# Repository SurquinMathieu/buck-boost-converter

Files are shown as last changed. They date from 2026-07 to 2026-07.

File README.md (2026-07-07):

# Buck-Boost DC/DC Converter

A 4-switch synchronous buck-boost converter built around an STM32G431CBT6, with a digital PI control loop, USB CDC telemetry, and a real-time web dashboard for monitoring and control.

## Overview

This project implements a 4-switch buck-boost DC/DC converter. The STM32 runs a 300 kHz PWM control loop with real-time voltage sensing, feedforward + PI regulation, soft-start, and software UVLO protection. A companion web dashboard connects over USB to display live VIN/VOUT readings and lets you adjust the output setpoint from a browser.

**Key specifications**

| Parameter | Value |
|---|---|
| Input voltage | 10 – 40 V |
| Output voltage | 3 – 15 V |
| Max output current| 3 A |
| Switching frequency | 300 kHz |
| MCU | STM32G431CBT6 (Cortex-M4, 170 MHz) |
| Topology | 4-switch buck-boost |

## Features

- Digital PI control with feedforward
- Soft-start on power-up and on setpoint changes
- Software UVLO (on: 12 V, off: 10 V) backed by a hardware UVLO on the gate-driver supply
- Dual-simultaneous ADC sampling of VIN and VOUT, triggered by the timer
- USB CDC telemetry (VIN, VOUT, target, duty cycle)
- Web dashboard (Python/WebSocket backend + HTML/JS frontend) for live plotting and setpoint control
- State-machine firmware architecture designed to be extended to boost and full buck-boost modes

## Hardware

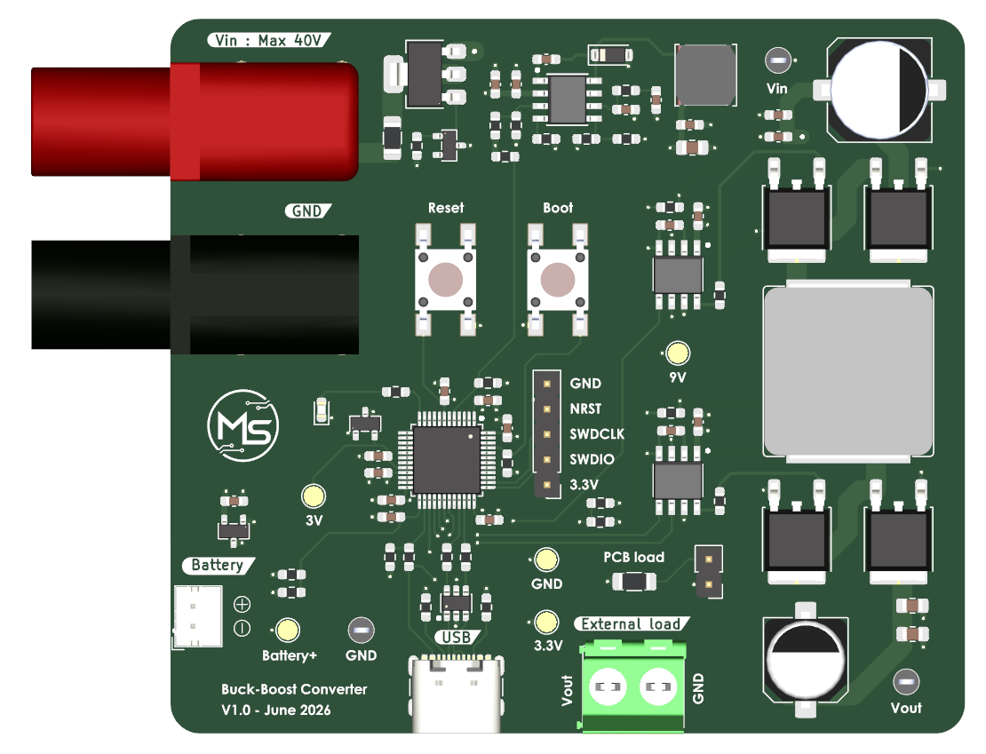
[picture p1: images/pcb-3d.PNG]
PCB


The converter uses four N-channel MOSFETs driven by two half-bridge gate drivers.

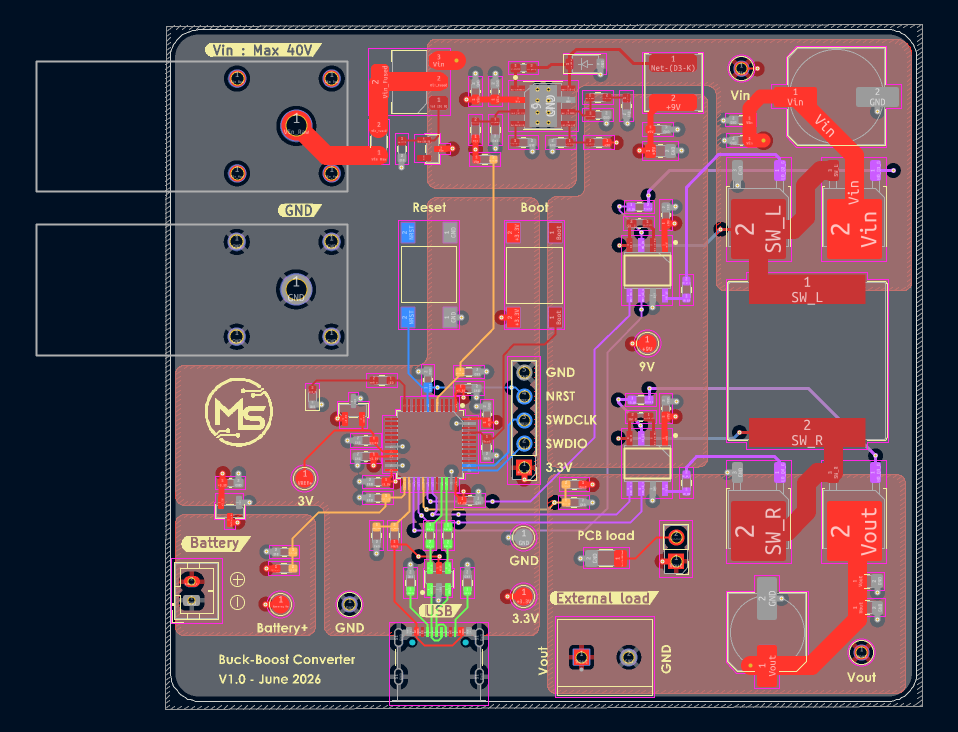
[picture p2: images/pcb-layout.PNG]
PCB layout


See [`hardware/kicad`](hardware/kicad) for the full KiCad project and [`hardware/bom`](hardware/bom) for the bill of materials.

## Firmware

See [`firmware/`](firmware) for the STM32CubeIDE project.

### Building

1. Open the project in STM32CubeIDE (`firmware/DC-DC-Converter.ioc`)
2. Build and flash to an STM32G431CBT6
3. Connect over USB

## Dashboard

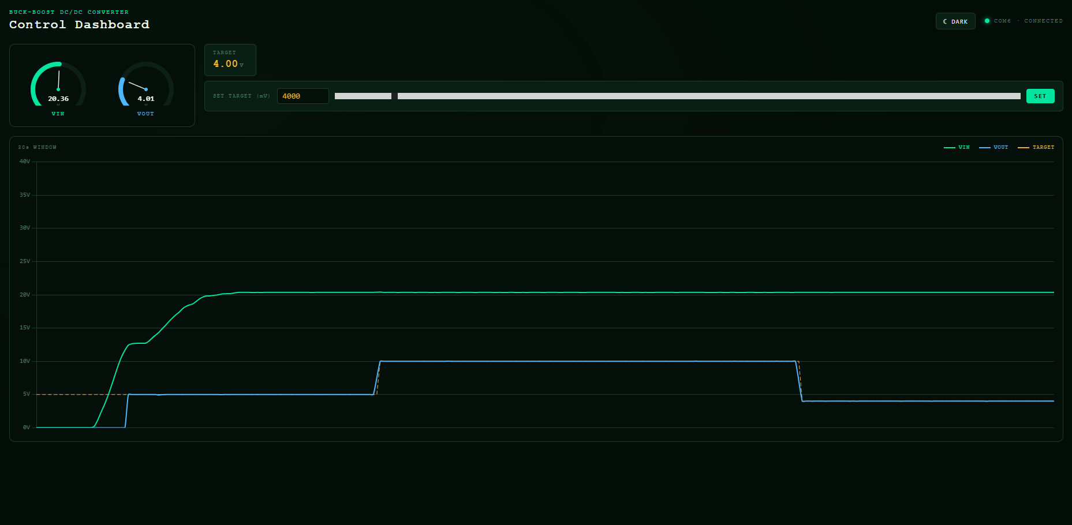
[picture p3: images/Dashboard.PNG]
Dashboard


The dashboard connects to the board's virtual COM port and streams VIN/VOUT/target data to a browser in real time over a local WebSocket, with a live waveform plot and a setpoint control.

### Running it

```bash
cd dashboard
pip install pyserial websockets
python server.py
```

Then open `index.html` in a browser. Update the `PORT` variable in `server.py` to match your board's COM port.

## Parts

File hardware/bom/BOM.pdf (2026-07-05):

Designator C1 | Qty 1 | Component Ceramic capacitor 560pF — 50V X7R — 0603 | Manufacturer Samsung | MPN / Reference CL10C561JB8NFNC | Unit Price (€) 0,039 € | Unit Price × Qty (€) 0,04 €
C2 – C17 | 16 | Ceramic capacitor 100nF — 50V X7R — 0603 | Samsung | CL10B104KB8NNNC | 0,023 € | 0,37 €
C18 | 1 | Ceramic capacitor 330nF — 50V X7R — 0603 | TDK | CGA3E3X7R1H334K080AB | 0,200 € | 0,20 €
C19 | 1 | Ceramic capacitor 1µF — 25V X7R — 0603 | Samsung | CL10B105KA8NNNC | 0,031 € | 0,03 €
C20, C21 | 2 | Ceramic capacitor 2.2µF — 50V X5R — 0603 | Murata | GRT188R61H225KE13D | 0,009 € | 0,02 €
C22, C23, C24 | 3 | Ceramic capacitor 10µF — 16V X5R — 0805 | Samsung | CL21A106KOQNNNE | 0,052 € | 0,16 €
C25 | 1 | Electrolytic Capacitor 100µF — 50V 20% — 10x10mm | Panasonic | EEH-ZA1H101V | 1,390 € | 1,39 €
C26 | 1 | Electrolytic Capacitor 220µF — 25V 20% — 8x8mm | Panasonic | EEH-ZA1E221P | 1,460 € | 1,46 €
D1 | 1 | Zener diode 10V 300mW — SOT-23 | Diotec Semiconductor | BZX84C10 | 0,150 € | 0,15 €
D2 | 1 | Red LED — 0603 | Würth Elektronik | 150060SS75000 | 0,130 € | 0,13 €
D3 | 1 | Schottky diode 60V 1A — SOD-123 | ROHM Semiconductor | RB162MM-60TR | 0,330 € | 0,33 €
D4 | 1 | TVS diode 5.25V bidirectional — SOT-23-6 | STMicroelectronics | USBLC6-2SC6Y | 0,460 € | 0,46 €
F1 | 1 | Fuse 6A — 1206 | Bel Fuse | 0685T6000-01 | 0,570 € | 0,57 €
J1 | 1 | Banana jack 4mm red | Cliff Electronic | FCR7350R | 4,870 € | 4,87 €
J2 | 1 | Banana jack 4mm black | Cliff Electronic | FCR7350B | 4,870 € | 4,87 €
J3 | 1 | Connector JST-PH 2-pin | JST | B2B-PH-K-S | 0,100 € | 0,10 €
J4 | 1 | USB Type-C 16P | GCT | USB4105-GF-A | 0,690 € | 0,69 €
J5 | 1 | Pin header 1×02 2.54mm vertical | — | — | 0,000 € | 0,00 €
J6 | 1 | Terminal block 2P 5.08mm | TE Connectivity | 282837-2 | 0,760 € | 0,76 €
J7 | 1 | Pin header 1×05 2.54mm vertical | — | — | 0,000 € | 0,00 €
L1 | 1 | Inductor 15µH 2.5A 75mΩ — 6x6mm | TDK | VLS6045EX-150M | 0,320 € | 0,32 €
L2 | 1 | Inductor 39µH 9.2A 48mΩ — 16,9x16,9mm | Bourns | SRP1770TA-390M | 3,170 € | 3,17 €
Q1, Q2, Q3, Q4 | 4 | MOSFET N-ch 60V 45A — TO-252-3 | Infineon | IPD053N06NATMA1 | 2,140 € | 8,56 €
Q5 | 1 | MOSFET P-ch 60V 18.2A — SOT-223 | Diodes Incorporated | DMP6023LE-13 | 1,110 € | 1,11 €
R1 – R4 | 4 | Resistor 4.7Ω 5% 1/8W — 0603 | Vishay | CRCW06034R70JNEA | 0,026 € | 0,10 €
R5, R6 | 2 | Resistor 22Ω 5% 1/5W — 0603 | TE Connectivity | CRGH0603J22R | 0,035 € | 0,07 €
R7 | 1 | Resistor 68Ω 1% 1/10W — 0603 | Yageo | RC0603FR-0768RL | 0,021 € | 0,02 €
R8 | 1 | Resistor 1kΩ 1% 1/2W — 1206 | Stackpole Electronics | RNCP1206FTD1K00 | 0,015 € | 0,02 €
R9 | 1 | Resistor 1.4kΩ 1% 1/10W — 0603 | Bourns | CR0603-FX-1401ELF | 0,019 € | 0,02 €
R10, R11 | 2 | Resistor 5.1kΩ 1% 1/10W — 0603 | Yageo | RC0603FR-075K1L | 0,021 € | 0,04 €
R12 – R15 | 4 | Resistor 10kΩ 1% 1/10W — 0603 | Yageo | RC0603FR-0710KL | 0,021 € | 0,08 €
R16 | 1 | Resistor 33kΩ 1% 1/10W — 0603 | Yageo | RC0603FR-0733KL | 0,021 € | 0,02 €
R17 | 1 | Resistor 40.2kΩ 1% 1/10W — 0603 | Yageo | RC0603FR-0740K2L | 0,021 € | 0,02 €
R18 | 1 | Resistor 61.9kΩ 1% 1/10W — 0603 | Bourns | CR0603-FX-6192ELF | 0,018 € | 0,02 €
R19 | 1 | Resistor 68kΩ 1% 1/10W — 0603 | Yageo | RC0603FR-0768KL | 0,021 € | 0,02 €
R20, R21 | 2 | Resistor 100kΩ 1% 1/10W — 0603 | Yageo | RC0603FR-07100KL | 0,021 € | 0,04 €
R22 | 1 | Resistor 102kΩ 0.1% 1/10W — 0603 | Yageo | RT0603BRD07102KL | 0,057 € | 0,06 €
R23 | 1 | Resistor 124kΩ 1% 1/10W — 0603 | Yageo | RC0603FR-07124KL | 0,021 € | 0,02 €
R24 | 1 | Resistor 180kΩ 1% 1/10W — 0603 | Yageo | RC0603FR-07180KL | 0,021 € | 0,02 €
R25 | 1 | Resistor 249kΩ 0.1% 1/10W — 0603 | Panasonic | ERA-3AEB2493V | 0,090 € | 0,09 €
R26 | 1 | Resistor 590kΩ 1% 1/8W — 0603 | Vishay | CRCW0603590KFKEA | 0,027 € | 0,03 €
SW1, SW2 | 2 | Switch SPST-NO 50mA 12V — SMD | Same Sky | TS04-66-50-BK-260-SMT | 0,151 € | 0,30 €
TP1, TP2, TP6 | 3 | Testpoint miniature | Keystone Electronics | 5001 | 0,260 € | 0,78 €
U1 | 1 | MCU STM32G431CBT6 — Cortex-M4 170MHz FPU — LQFP-48 | STMicroelectronics | STM32G431CBT6 | 5,150 € | 5,15 €
U2 | 1 | LDO 3.3V 250mA — SOT-23 | Microchip Technology | MCP1700T-3302E/TT | 0,440 € | 0,44 €
U3 | 1 | Voltage reference 3.000V 0.1% — SOT-23 | Texas Instruments | REF3030EAIDBZR | 1,010 € | 1,01 €
U4 | 1 | Buck converter — HSOIC-8 | Texas Instruments | TPS54360BDDAR | 3,980 € | 3,98 €
U5, U6 | 2 | Half-bridge gate driver — SOIC-8 | Texas Instruments | UCC27282DR | 1,700 € | 3,40 €
TOTAL | 82 | | | | | 45,51 €

## BILL OF MATERIALS — Buck-Boost DC/DC Converter

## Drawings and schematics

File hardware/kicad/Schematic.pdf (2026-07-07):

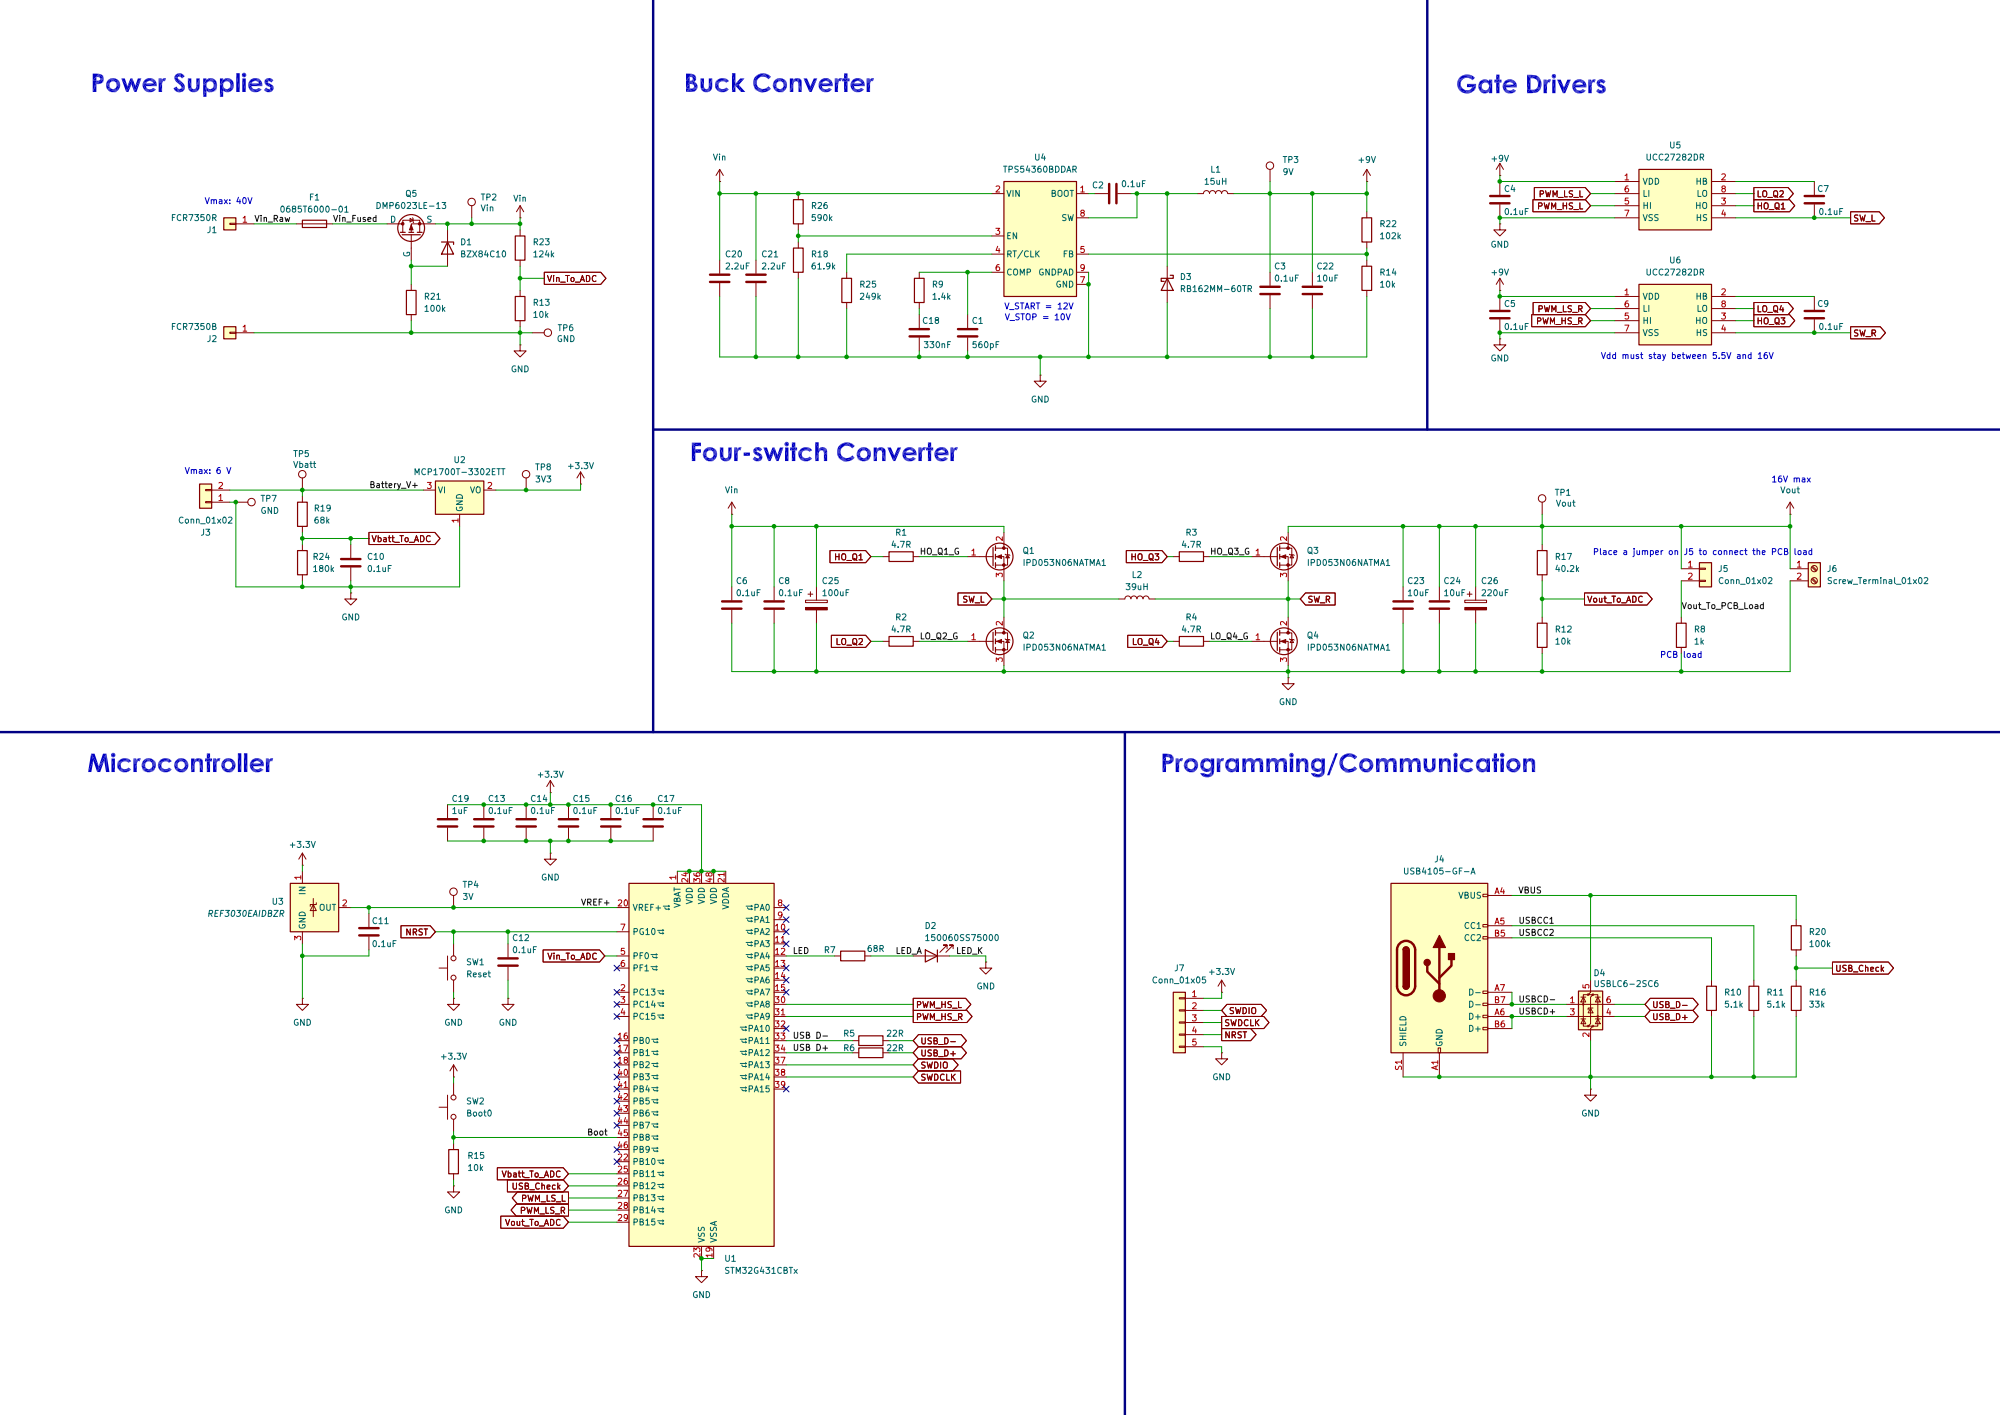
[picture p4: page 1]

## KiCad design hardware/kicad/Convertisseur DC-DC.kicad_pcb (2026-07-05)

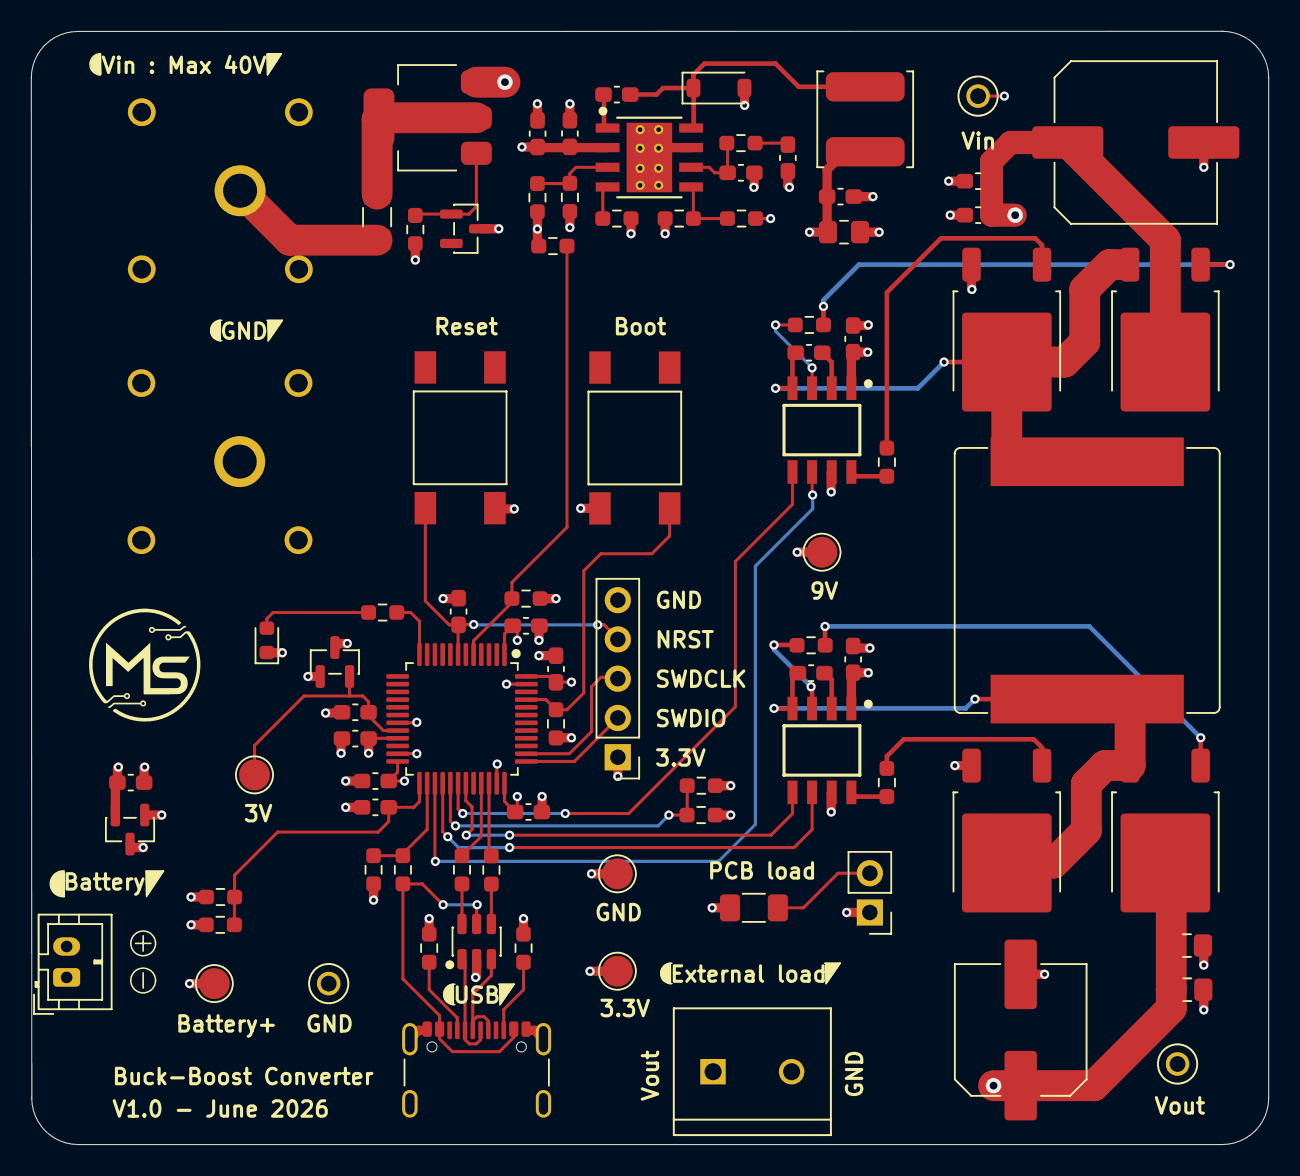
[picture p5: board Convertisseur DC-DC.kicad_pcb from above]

Board: 4 copper layers, 80.0 x 72.0 mm, 87 parts (0 on the bottom side), 53 nets.

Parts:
C1: 560pF; C_0603_1608Metric_Pad1.08x0.95mm_HandSolder
C2, C3, C4, C5, C6, C7, C8, C9, C10, C11, C12, C13, C14, C15, C16, C17: 0.1uF; C_0603_1608Metric_Pad1.08x0.95mm_HandSolder
C18: 330nF; C_0603_1608Metric_Pad1.08x0.95mm_HandSolder
C19: 1uF; C_0603_1608Metric_Pad1.08x0.95mm_HandSolder
C20, C21: 2.2uF; C_0603_1608Metric_Pad1.08x0.95mm_HandSolder
C22, C23, C24: 10uF; C_0805_2012Metric_Pad1.18x1.45mm_HandSolder
C25: 100uF; C_Elec_10x10.2
C26: 220uF; C_Elec_8x10.2
D1: BZX84C10; SOT-23
D2: 150060SS75000; LED_0603_1608Metric
D3: RB162MM-60TR; D_SOD-123
D4: USBLC6-2SC6; SOT-23-6
F1: 0685T6000-01; Fuse_1206_3216Metric_Pad1.42x1.75mm_HandSolder
J1: FCR7350R; FCR7350
J2: FCR7350B; FCR7350
J3: Conn_01x02; JST_PH_B2B-PH-K_1x02_P2.00mm_Vertical
J4: USB4105-GF-A; USB_C_Receptacle_GCT_USB4105-xx-A_16P_TopMnt_Horizontal
J5: Conn_01x02; PinHeader_1x02_P2.54mm_Vertical
J6: Screw_Terminal_01x02; TE_282837-2
J7: Conn_01x05; PinHeader_1x05_P2.54mm_Vertical
L1: 15uH; L_TDK_VLS6045EX_VLS6045AF
L2: 39uH; L_Bourns_SRP1770TA_16.9x16.9mm
Q1, Q2, Q3, Q4: IPD053N06NATMA1; TO-252-2
Q5: DMP6023LE-13; SOT-223-3_TabPin2
R1, R2, R3, R4: 4.7R; R_0603_1608Metric_Pad0.98x0.95mm_HandSolder
R5, R6: 22R; R_0603_1608Metric_Pad0.98x0.95mm_HandSolder
R7: 68R; R_0603_1608Metric_Pad0.98x0.95mm_HandSolder
R8: 1k; R_1206_3216Metric_Pad1.30x1.75mm_HandSolder
R9: 1.4k; R_0603_1608Metric_Pad0.98x0.95mm_HandSolder
R10, R11: 5.1k; R_0603_1608Metric_Pad0.98x0.95mm_HandSolder
R12, R13, R14, R15: 10k; R_0603_1608Metric_Pad0.98x0.95mm_HandSolder
R16: 33k; R_0603_1608Metric_Pad0.98x0.95mm_HandSolder
R17: 40.2k; R_0603_1608Metric_Pad0.98x0.95mm_HandSolder
R18: 61.9k; R_0603_1608Metric_Pad0.98x0.95mm_HandSolder
R19: 68k; R_0603_1608Metric_Pad0.98x0.95mm_HandSolder
R20, R21: 100k; R_0603_1608Metric_Pad0.98x0.95mm_HandSolder
R22: 102k; R_0603_1608Metric_Pad0.98x0.95mm_HandSolder
R23: 124k; R_0603_1608Metric_Pad0.98x0.95mm_HandSolder
R24: 180k; R_0603_1608Metric_Pad0.98x0.95mm_HandSolder
R25: 249k; R_0603_1608Metric_Pad0.98x0.95mm_HandSolder
R26: 590k; R_0603_1608Metric_Pad0.98x0.95mm_HandSolder
SW1: Reset; SW_TS04-66-50-BK-260-SMT
SW2: Boot0; SW_TS04-66-50-BK-260-SMT
TP1: Vout; 5001
TP2: Vin; 5001
TP3: 9V; TestPoint_Pad_D2.0mm
TP4: 3V; TestPoint_Pad_D2.0mm
TP5: Vbatt; TestPoint_Pad_D2.0mm
TP6: GND; 5001
TP7: GND; TestPoint_Pad_D2.0mm
TP8: 3V3; TestPoint_Pad_D2.0mm
U1: STM32G431CBTx; LQFP-48_7x7mm_P0.5mm
U2: MCP1700T-3302ETT; SOT-23
U3: REF3030EAIDBZR; SOT-23
U4: TPS54360BDDAR; TI_SO-PowerPAD-8_ThermalVias
U5, U6: UCC27282DR

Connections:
+3.3V: C13.1, C14.1, C15.1, C16.1, C17.1, C19.1, J7.1, SW2.2, TP8.1, U1.1 (VBAT), U1.21 (VDDA), U1.24 (VDD), U1.36 (VDD), U1.48 (VDD), U2.2 (VO), U3.1 (IN)
+9V: C3.1, C4.1, C5.1, C22.1, L1.2, R22.1, TP3.1, U5.1 (VDD), U6.1 (VDD)
/Battery_V+: J3.2, R19.1, TP5.1, U2.3 (VI)
/Boot: R15.1, SW2.1, U1.45 (PB8)
/HO_Q1_G: Q1.1 (G), R1.2
/HO_Q3_G: Q3.1 (G), R3.2
/LED: R7.1, U1.12 (PA4)
/LED_A: D2.2 (A), R7.2
/LO_Q2_G: Q2.1 (G), R2.2
/LO_Q4_G: Q4.1 (G), R4.2
/USB D+: R6.1, U1.34 (PA12)
/USB D-: R5.1, U1.33 (PA11)
/USBCC1: J4.A5 (CC1), R11.1
/USBCC2: J4.B5 (CC2), R10.1
/USBCD+: D4.3 (I/O2), J4.A6 (D+), J4.B6 (D+)
/USBCD-: D4.1 (I/O1), J4.A7 (D-), J4.B7 (D-)
/VBUS: D4.5 (VBUS), J4.A4 (VBUS), J4.A9 (VBUS), J4.B4 (VBUS), J4.B9 (VBUS), R20.1
/VREF+: C11.1, TP4.1, U1.20 (VREF+), U3.2 (OUT)
/Vin_Fused: F1.2, Q5.2 (D)
/Vin_Raw: F1.1, J1.1
/Vout_To_PCB_Load: J5.2, R8.1
GND: C1.2, C3.2, C4.2, C5.2, C6.2, C8.2, C10.2, C11.2, C12.2, C13.2, C14.2, C15.2, C16.2, C17.2, C18.2, C19.2, C20.2, C21.2, C22.2, C23.2, C24.2, C25.2, C26.2, D2.1 (K), D3.2 (A), D4.2 (GND), J2.1, J3.1, J4.A1 (GND), J4.A12 (GND), J4.B1 (GND), J4.B12 (GND), J4.S1 (SHIELD), J6.2, J7.5, Q2.3 (S), Q4.3 (S), R8.2, R10.2, R11.2, R12.2, R13.2, R14.2, R15.2, R16.2, R18.2, R21.2, R24.2, R25.2, SW1.1, TP6.1, TP7.1, U1.19 (VSSA), U1.23 (VSS), U1.35 (VSS), U1.47 (VSS), U2.1 (GND), U3.3 (GND), U4.7 (GND), U4.9 (GNDPAD), U5.7 (VSS), U6.7 (VSS)
HO_Q1: R1.1, U5.3 (HO)
HO_Q3: R3.1, U6.3 (HO)
LO_Q2: R2.1, U5.8 (LO)
LO_Q4: R4.1, U6.8 (LO)
NRST: C12.1, J7.4, SW1.2, U1.7 (PG10)
unnamed: C18.1, R9.2
unnamed: D1.1 (A), Q5.1 (G), R21.1
unnamed: C2.2, D3.1 (K), L1.1, U4.8 (SW)
unnamed: C2.1, U4.1 (BOOT)
unnamed: C1.1, R9.1, U4.6 (COMP)
unnamed: R18.1, R26.2, U4.3 (EN)
unnamed: R14.1, R22.2, U4.5 (FB)
unnamed: R25.1, U4.4 (RT/CLK)
unnamed: C7.1, U5.2 (HB)
unnamed: C9.1, U6.2 (HB)
PWM_HS_L: U1.30 (PA8), U5.5 (HI)
PWM_HS_R: U1.31 (PA9), U6.5 (HI)
PWM_LS_L: U1.27 (PB13), U5.6 (LI)
PWM_LS_R: U1.28 (PB14), U6.6 (LI)
SWDCLK: J7.3, U1.38 (PA14)
SWDIO: J7.2, U1.37 (PA13)
SW_L: C7.2, L2.1, Q1.3 (S), Q2.2 (D), U5.4 (HS)
SW_R: C9.2, L2.2, Q3.3 (S), Q4.2 (D), U6.4 (HS)
USB_Check: R16.1, R20.2, U1.26 (PB12)
USB_D+: D4.4 (I/O2), R6.2
USB_D-: D4.6 (I/O1), R5.2
Vbatt_To_ADC: C10.1, R19.2, R24.1, U1.25 (PB11)
Vin: C6.1, C8.1, C20.1, C21.1, C25.1, D1.3 (K), Q1.2 (D), Q5.3 (S), R23.1, R26.1, TP2.1, U4.2 (VIN)
Vin_To_ADC: R13.1, R23.2, U1.5 (PF0)
Vout: C23.1, C24.1, C26.1, J5.1, J6.1, Q3.2 (D), R17.1, TP1.1
Vout_To_ADC: R12.1, R17.2, U1.29 (PB15)

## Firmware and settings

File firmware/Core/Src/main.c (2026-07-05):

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

/* Includes ------------------------------------------------------------------*/
#include "main.h"
#include "usb_device.h"
/* USER CODE BEGIN Includes */
#include "usbd_cdc_if.h"
#include <stdio.h>
#include <string.h>
/* USER CODE END Includes */

/* USER CODE BEGIN PTD */

/**
 * @brief Operating mode of the converter
 *
 * Only MODE_BUCK is currently implemented
 */
typedef enum {
    MODE_BUCK = 0,
    MODE_BOOST,
    MODE_BUCK_BOOST
} ConverterMode_t;

/**
 * @brief Internal state machine of the converter
 *
 * STATE_IDLE      : VIN below UVLO threshold — PWM off
 * STATE_SOFTSTART : PWM ramping up toward the target
 * STATE_RUNNING   : PI controller fully active
 */
typedef enum {
    STATE_IDLE = 0,
    STATE_SOFTSTART,
    STATE_RUNNING
} ConverterState_t;

/* USER CODE END PTD */

/* USER CODE BEGIN PD */

/* TIM1 period register (ARR) */
#define TIM1_ARR            566U

/* UVLO thresholds in mV */
#define UVLO_ON_MV          12000U
#define UVLO_OFF_MV         10000U

/* ADC conversion factors */
#define ADC_VREF_MV         3000.0f
#define ADC_FULL_SCALE      4095.0f
#define VIN_DIVIDER_FACTOR  13.4f
#define VOUT_DIVIDER_FACTOR 5.02f

/* VOUT limits in mV */
#define VOUT_MIN_MV         3000U
#define VOUT_MAX_MV         15000U

/* Boost maximum duty */
#define DUTY_BOOST_MAX      550

/* Soft-start: one duty step every N control-loop cycles */
#define SOFTSTART_STEP_PERIOD   4U

/* USB data send interval in ms */
#define USB_SEND_INTERVAL_MS    100U

/* USER CODE END PD */

ADC_HandleTypeDef hadc1;
ADC_HandleTypeDef hadc2;
TIM_HandleTypeDef htim1;

/* USER CODE BEGIN PV */

/* ── Converter configuration ─────────────────────────────────────────────── */
static ConverterMode_t  converter_mode  = MODE_BUCK;
static ConverterState_t converter_state = STATE_IDLE;

/* ── Measurements ────────────────────── */
volatile uint32_t vin_mv  = 0;
volatile uint32_t vout_mv = 0;

/* ── Setpoint (may be updated from USB) ──────────────────────────────────── */
volatile uint32_t vout_target_mv = 5000;

/* ── PI controller state ─────────────────────────────────────────────────── */
volatile float Kp             = 0.1f;
volatile float Ki             = 0.001f;
volatile float pi_integral    = 0.0f;
volatile float pi_integral_max = 100000.0f;

/* ── PWM duty cycle ─────────────────────────────────────── */
volatile int32_t duty = 0;

/* USER CODE END PV */

void SystemClock_Config(void);
static void MX_GPIO_Init(void);
static void MX_TIM1_Init(void);
static void MX_ADC1_Init(void);
static void MX_ADC2_Init(void);

/* USER CODE BEGIN PFP */
static void     mode_init(ConverterMode_t mode);
static void     measurements_update(void);
static uint8_t  uvlo_check(void);
static void     setpoint_check(void);
static int32_t  compute_feedforward(void);
static int32_t  pi_update(int32_t error);
static int32_t  duty_clamp(int32_t raw_duty);
static void     softstart_update(int32_t duty_target);
static void     pwm_apply(void);
static void     pwm_stop(void);
/* USER CODE END PFP */

/* USER CODE BEGIN 0 */

/**
 * @brief Configure GPIOs for the selected converter mode
 *
 * Buck  : Q3 (PA9) permanently ON, Q4 (PB14) permanently OFF
 *         Q1/Q2 switch via TIM1 CH1/CH1N
 * Boost : Q1 (PA8) permanently ON, Q2 (PB13) permanently OFF
 *         Q3/Q4 switch via TIM1 CH2/CH2N
 */
static void mode_init(ConverterMode_t mode)
{
    switch (mode)
    {
        case MODE_BUCK:
            HAL_GPIO_WritePin(GPIOA, GPIO_PIN_9,  GPIO_PIN_SET);   /* Q3 ON  */
            HAL_GPIO_WritePin(GPIOB, GPIO_PIN_14, GPIO_PIN_RESET); /* Q4 OFF */
            break;

        case MODE_BOOST:
            /* TODO */
            break;

        case MODE_BUCK_BOOST:
            /* TODO */
            break;
    }
}

/**
 * @brief Read ADC dual-simultaneous result and convert to millivolts
 *
 * CDR bits [15:0]  = ADC1 (VIN),  bits [31:16] = ADC2 (VOUT)
 */
static void measurements_update(void)
{
    uint32_t cdr = ADC12_COMMON->CDR;
    uint32_t vin_raw  = cdr & 0xFFFFU;
    uint32_t vout_raw = (cdr >> 16) & 0xFFFFU;

    vin_mv  = (uint32_t)(vin_raw  / ADC_FULL_SCALE * ADC_VREF_MV * VIN_DIVIDER_FACTOR);
    vout_mv = (uint32_t)(vout_raw / ADC_FULL_SCALE * ADC_VREF_MV * VOUT_DIVIDER_FACTOR);
}

/**
 * @brief Evaluate UVLO condition and update converter state accordingly
 *
 * @return 1 if the converter must stay in IDLE
 *         0 if VIN is within operating range
 */
static uint8_t uvlo_check(void)
{
    if (vin_mv >= UVLO_ON_MV)
    {
        if (converter_state == STATE_IDLE)
        {
            /* VIN just crossed the ON threshold — begin soft-start */
            duty         = 0;
            pi_integral  = 0.0f;
            converter_state = STATE_SOFTSTART;
        }
        return 0;
    }

    if (vin_mv < UVLO_OFF_MV)
    {
        converter_state = STATE_IDLE;
        duty            = 0;
        pi_integral     = 0.0f;
        pwm_stop();
        return 1;
    }

    /* Hysteresis band: keep current state */
    return (converter_state == STATE_IDLE) ? 1U : 0U;
}

/**
 * @brief Clamp vout_target_mv to valid range and relaunch soft-start whenever the setpoint changes
 */
static void setpoint_check(void)
{
    if (vout_target_mv < VOUT_MIN_MV) vout_target_mv = VOUT_MIN_MV;
    if (vout_target_mv > VOUT_MAX_MV) vout_target_mv = VOUT_MAX_MV;

    /* Boost: target must stay above VIN */
    if (converter_mode == MODE_BOOST && vout_target_mv < vin_mv + 500U)
        vout_target_mv = vin_mv + 500U;

    static uint32_t prev_target_mv = 0;
    if (vout_target_mv != prev_target_mv)
    {
        prev_target_mv  = vout_target_mv;
        converter_state = STATE_SOFTSTART;
    }
}

/**
 * @brief Compute the open-loop feedforward duty cycle for the active mode
 *
 * The feedforward provides a starting point close to the correct duty so the PI only needs to correct the residual error
 *
 * @return Raw feedforward duty (not yet clamped)
 */
static int32_t compute_feedforward(void)
{
    if (vin_mv == 0) return 0;

    switch (converter_mode)
    {
        case MODE_BUCK:
            return (int32_t)((float)vout_target_mv / (float)vin_mv * TIM1_ARR);

        case MODE_BOOST:
            return (int32_t)(TIM1_ARR - (float)vin_mv / (float)vout_target_mv * TIM1_ARR);

        case MODE_BUCK_BOOST:
            return (int32_t)((float)vout_target_mv / ((float)vin_mv + (float)vout_target_mv) * TIM1_ARR);

        default:
            return 0;
    }
}

/**
 * @brief Run one PI iteration
 *
 * The same PI algorithm is used for all converter modes. Only the feedforward is mode-dependent
 *
 * @return PI correction term (to be added to feedforward)
 */
static int32_t pi_update(int32_t error)
{
    int32_t p_term = (int32_t)(Kp * (float)error);

    pi_integral += Ki * (float)error;
    if (pi_integral >  pi_integral_max) pi_integral =  pi_integral_max;
    if (pi_integral < -pi_integral_max) pi_integral = -pi_integral_max;

    int32_t i_term = (int32_t)pi_integral;

    return p_term + i_term;
}

/**
 * @brief Clamp a raw duty value to the valid range for the active mode
 */
static int32_t duty_clamp(int32_t raw_duty)
{
    int32_t max_duty;

    switch (converter_mode)
    {
        case MODE_BOOST:
            max_duty = DUTY_BOOST_MAX;
            break;
        case MODE_BUCK:
        case MODE_BUCK_BOOST:
        default:
            max_duty = (int32_t)TIM1_ARR;
            break;
    }

    if (raw_duty < 0)        return 0;
    if (raw_duty > max_duty) return max_duty;
    return raw_duty;
}

/**
 * @brief Advance the duty cycle toward duty_target by one soft-start step
 *
 * While in STATE_SOFTSTART, duty moves ±1 every SOFTSTART_STEP_PERIOD control cycles
 * Once duty == duty_target the state transitions to STATE_RUNNING and full PI control takes over
 */
static void softstart_update(int32_t duty_target)
{
    static uint8_t step_counter = 0;
    step_counter++;
    if (step_counter >= SOFTSTART_STEP_PERIOD)
    {
        step_counter = 0;
        if      (duty < duty_target) duty++;
        else if (duty > duty_target) duty--;
        else                         converter_state = STATE_RUNNING;
    }
}

/**
 * @brief Write the current duty value to the appropriate CCR register
 */
static void pwm_apply(void)
{
    switch (converter_mode)
    {
        case MODE_BUCK:
            TIM1->CCR1 = (uint32_t)duty;
            break;

        case MODE_BOOST:
            TIM1->CCR2 = (uint32_t)duty;
            break;

        case MODE_BUCK_BOOST:
            /* TODO */
            break;
    }
}

/**
 * @brief Force all PWM outputs to zero (UVLO or fault condition)
 */
static void pwm_stop(void)
{
    TIM1->CCR1 = 0;
    TIM1->CCR2 = 0;
}

/**
 * @brief TIM1 period-elapsed ISR — main control loop (150 kHz)
 *
 */
void HAL_TIM_PeriodElapsedCallback(TIM_HandleTypeDef *htim)
{
    if (htim->Instance != TIM1) return;

    /* 1. Measurements */
    measurements_update();

    /* 2. UVLO */
    if (uvlo_check()) return;

    /* 3. Clamp setpoint + detect setpoint change */
    setpoint_check();

    /* 4. Feedforward + PI */
    int32_t duty_new = compute_feedforward()
                     + pi_update((int32_t)vout_target_mv - (int32_t)vout_mv);
    duty_new = duty_clamp(duty_new);

    /* 5. Apply duty */
    if (converter_state == STATE_SOFTSTART)
        softstart_update(duty_new);
    else
        duty = duty_new;

    /* 6. Apply */
    pwm_apply();
}

/* USER CODE END 0 */

int main(void)
{
    HAL_Init();

    SystemClock_Config();

    MX_GPIO_Init();
    MX_USB_Device_Init();
    MX_TIM1_Init();
    MX_ADC1_Init();
    MX_ADC2_Init();

    /* USER CODE BEGIN 2 */

    /* Configure GPIOs for the selected mode */
    mode_init(converter_mode);

    /* Start PWM outputs */
    HAL_TIM_PWM_Start(&htim1, TIM_CHANNEL_1);
    HAL_TIMEx_PWMN_Start(&htim1, TIM_CHANNEL_1);

    /* Start control-loop interrupt */
    HAL_TIM_Base_Start_IT(&htim1);

    /* Release PF0 (ADC1_IN10 / VIN) from HSE oscillator function */
    RCC->CR &= ~RCC_CR_HSEON;

    /* Calibrate and start ADC in dual simultaneous mode */
    HAL_ADCEx_Calibration_Start(&hadc1, ADC_SINGLE_ENDED);
    HAL_ADCEx_Calibration_Start(&hadc2, ADC_SINGLE_ENDED);
    HAL_ADC_Start(&hadc2);
    HAL_ADC_Start(&hadc1);

    uint32_t last_usb_send = 0;

    /* USER CODE END 2 */

    /* USER CODE BEGIN WHILE */
    while (1)
    {
        /* USER CODE END WHILE */

        /* USER CODE BEGIN 3 */

        /* USB data sent to web dashboard */
        if (HAL_GetTick() - last_usb_send >= USB_SEND_INTERVAL_MS)
        {
            last_usb_send = HAL_GetTick();

            char msg[80];
            sprintf(msg, "VIN:%u VOUT:%u TARGET:%u DUTY:%d\r\n",
                    (unsigned int)vin_mv,
                    (unsigned int)vout_mv,
                    (unsigned int)vout_target_mv,
                    (int)duty);
            CDC_Transmit_FS((uint8_t*)msg, strlen(msg));
        }

        /* USER CODE END 3 */
    }
}

void SystemClock_Config(void)
{
    RCC_OscInitTypeDef RCC_OscInitStruct = {0};
    RCC_ClkInitTypeDef RCC_ClkInitStruct = {0};

    HAL_PWREx_ControlVoltageScaling(PWR_REGULATOR_VOLTAGE_SCALE1_BOOST);

    RCC_OscInitStruct.OscillatorType      = RCC_OSCILLATORTYPE_HSI
                                          | RCC_OSCILLATORTYPE_HSI48;
    RCC_OscInitStruct.HSIState            = RCC_HSI_ON;
    RCC_OscInitStruct.HSICalibrationValue = RCC_HSICALIBRATION_DEFAULT;
    RCC_OscInitStruct.HSI48State          = RCC_HSI48_ON;
    RCC_OscInitStruct.PLL.PLLState        = RCC_PLL_ON;
    RCC_OscInitStruct.PLL.PLLSource       = RCC_PLLSOURCE_HSI;
    RCC_OscInitStruct.PLL.PLLM            = RCC_PLLM_DIV4;
    RCC_OscInitStruct.PLL.PLLN            = 85;
    RCC_OscInitStruct.PLL.PLLP            = RCC_PLLP_DIV2;
    RCC_OscInitStruct.PLL.PLLQ            = RCC_PLLQ_DIV2;
    RCC_OscInitStruct.PLL.PLLR            = RCC_PLLR_DIV2;
    if (HAL_RCC_OscConfig(&RCC_OscInitStruct) != HAL_OK) Error_Handler();

    RCC_ClkInitStruct.ClockType      = RCC_CLOCKTYPE_HCLK  | RCC_CLOCKTYPE_SYSCLK
                                     | RCC_CLOCKTYPE_PCLK1 | RCC_CLOCKTYPE_PCLK2;
    RCC_ClkInitStruct.SYSCLKSource   = RCC_SYSCLKSOURCE_PLLCLK;
    RCC_ClkInitStruct.AHBCLKDivider  = RCC_SYSCLK_DIV1;
    RCC_ClkInitStruct.APB1CLKDivider = RCC_HCLK_DIV1;
    RCC_ClkInitStruct.APB2CLKDivider = RCC_HCLK_DIV1;
    if (HAL_RCC_ClockConfig(&RCC_ClkInitStruct, FLASH_LATENCY_4) != HAL_OK)
        Error_Handler();
}

static void MX_ADC1_Init(void)
{
    ADC_MultiModeTypeDef  multimode = {0};
    ADC_ChannelConfTypeDef sConfig  = {0};

    hadc1.Instance                   = ADC1;
    hadc1.Init.ClockPrescaler        = ADC_CLOCK_SYNC_PCLK_DIV4;
    hadc1.Init.Resolution            = ADC_RESOLUTION_12B;
    hadc1.Init.DataAlign             = ADC_DATAALIGN_RIGHT;
    hadc1.Init.GainCompensation      = 0;
    hadc1.Init.ScanConvMode          = ADC_SCAN_DISABLE;
    hadc1.Init.EOCSelection          = ADC_EOC_SEQ_CONV;
    hadc1.Init.LowPowerAutoWait      = DISABLE;
    hadc1.Init.ContinuousConvMode    = DISABLE;
    hadc1.Init.NbrOfConversion       = 1;
    hadc1.Init.DiscontinuousConvMode = DISABLE;
    hadc1.Init.ExternalTrigConv      = ADC_EXTERNALTRIG_T1_TRGO;
    hadc1.Init.ExternalTrigConvEdge  = ADC_EXTERNALTRIGCONVEDGE_RISING;
    hadc1.Init.DMAContinuousRequests = DISABLE;
    hadc1.Init.Overrun               = ADC_OVR_DATA_OVERWRITTEN;
    hadc1.Init.OversamplingMode      = DISABLE;
    if (HAL_ADC_Init(&hadc1) != HAL_OK) Error_Handler();

    multimode.Mode             = ADC_DUALMODE_REGSIMULT;
    multimode.DMAAccessMode    = ADC_DMAACCESSMODE_DISABLED;
    multimode.TwoSamplingDelay = ADC_TWOSAMPLINGDELAY_1CYCLE;
    if (HAL_ADCEx_MultiModeConfigChannel(&hadc1, &multimode) != HAL_OK)
        Error_Handler();

    sConfig.Channel      = ADC_CHANNEL_10;       /* PF0 — VIN */
    sConfig.Rank         = ADC_REGULAR_RANK_1;
    sConfig.SamplingTime = ADC_SAMPLETIME_47CYCLES_5;
    sConfig.SingleDiff   = ADC_SINGLE_ENDED;
    sConfig.OffsetNumber = ADC_OFFSET_NONE;
    sConfig.Offset       = 0;
    if (HAL_ADC_ConfigChannel(&hadc1, &sConfig) != HAL_OK) Error_Handler();
}

static void MX_ADC2_Init(void)
{
    ADC_ChannelConfTypeDef sConfig = {0};

    hadc2.Instance                   = ADC2;
    hadc2.Init.ClockPrescaler        = ADC_CLOCK_SYNC_PCLK_DIV4;
    hadc2.Init.Resolution            = ADC_RESOLUTION_12B;
    hadc2.Init.DataAlign             = ADC_DATAALIGN_RIGHT;
    hadc2.Init.GainCompensation      = 0;
    hadc2.Init.ScanConvMode          = ADC_SCAN_DISABLE;
    hadc2.Init.EOCSelection          = ADC_EOC_SEQ_CONV;
    hadc2.Init.LowPowerAutoWait      = DISABLE;
    hadc2.Init.ContinuousConvMode    = DISABLE;
    hadc2.Init.NbrOfConversion       = 1;
    hadc2.Init.DiscontinuousConvMode = DISABLE;
    hadc2.Init.DMAContinuousRequests = DISABLE;
    hadc2.Init.Overrun               = ADC_OVR_DATA_OVERWRITTEN;
    hadc2.Init.OversamplingMode      = DISABLE;
    if (HAL_ADC_Init(&hadc2) != HAL_OK) Error_Handler();

    sConfig.Channel      = ADC_CHANNEL_15;       /* PB15 — VOUT */
    sConfig.Rank         = ADC_REGULAR_RANK_1;
    sConfig.SamplingTime = ADC_SAMPLETIME_47CYCLES_5;
    sConfig.SingleDiff   = ADC_SINGLE_ENDED;
    sConfig.OffsetNumber = ADC_OFFSET_NONE;
    sConfig.Offset       = 0;
    if (HAL_ADC_ConfigChannel(&hadc2, &sConfig) != HAL_OK) Error_Handler();
}

static void MX_TIM1_Init(void)
{
    TIM_ClockConfigTypeDef       sClockSourceConfig = {0};
    TIM_MasterConfigTypeDef      sMasterConfig      = {0};
    TIM_OC_InitTypeDef           sConfigOC          = {0};
    TIM_BreakDeadTimeConfigTypeDef sBreakDeadTimeConfig = {0};

    htim1.Instance               = TIM1;
    htim1.Init.Prescaler         = 0;
    htim1.Init.CounterMode       = TIM_COUNTERMODE_UP;
    htim1.Init.Period            = TIM1_ARR;
    htim1.Init.ClockDivision     = TIM_CLOCKDIVISION_DIV1;
    htim1.Init.RepetitionCounter = 1;           /* ISR at 150 kHz */
    htim1.Init.AutoReloadPreload = TIM_AUTORELOAD_PRELOAD_ENABLE;
    if (HAL_TIM_Base_Init(&htim1) != HAL_OK) Error_Handler();

    sClockSourceConfig.ClockSource = TIM_CLOCKSOURCE_INTERNAL;
    if (HAL_TIM_ConfigClockSource(&htim1, &sClockSourceConfig) != HAL_OK)
        Error_Handler();

    if (HAL_TIM_PWM_Init(&htim1) != HAL_OK) Error_Handler();

    sMasterConfig.MasterOutputTrigger  = TIM_TRGO_UPDATE; /* ADC trigger */
    sMasterConfig.MasterOutputTrigger2 = TIM_TRGO2_RESET;
    sMasterConfig.MasterSlaveMode      = TIM_MASTERSLAVEMODE_DISABLE;
    if (HAL_TIMEx_MasterConfigSynchronization(&htim1, &sMasterConfig) != HAL_OK)
        Error_Handler();

    sConfigOC.OCMode       = TIM_OCMODE_PWM1;
    sConfigOC.Pulse        = 283;
    sConfigOC.OCPolarity   = TIM_OCPOLARITY_HIGH;
    sConfigOC.OCNPolarity  = TIM_OCNPOLARITY_HIGH;
    sConfigOC.OCFastMode   = TIM_OCFAST_DISABLE;
    sConfigOC.OCIdleState  = TIM_OCIDLESTATE_RESET;
    sConfigOC.OCNIdleState = TIM_OCNIDLESTATE_RESET;
    if (HAL_TIM_PWM_ConfigChannel(&htim1, &sConfigOC, TIM_CHANNEL_1) != HAL_OK)
        Error_Handler();

    sBreakDeadTimeConfig.OffStateRunMode  = TIM_OSSR_ENABLE;
    sBreakDeadTimeConfig.OffStateIDLEMode = TIM_OSSI_ENABLE;
    sBreakDeadTimeConfig.LockLevel        = TIM_LOCKLEVEL_OFF;
    sBreakDeadTimeConfig.DeadTime         = 20; /* ~118 ns @ 170 MHz */
    sBreakDeadTimeConfig.BreakState       = TIM_BREAK_DISABLE;
    sBreakDeadTimeConfig.BreakPolarity    = TIM_BREAKPOLARITY_HIGH;
    sBreakDeadTimeConfig.BreakFilter      = 0;
    sBreakDeadTimeConfig.BreakAFMode      = TIM_BREAK_AFMODE_INPUT;
    sBreakDeadTimeConfig.Break2State      = TIM_BREAK2_DISABLE;
    sBreakDeadTimeConfig.Break2Polarity   = TIM_BREAK2POLARITY_HIGH;
    sBreakDeadTimeConfig.Break2Filter     = 0;
    sBreakDeadTimeConfig.Break2AFMode     = TIM_BREAK_AFMODE_INPUT;
    sBreakDeadTimeConfig.AutomaticOutput  = TIM_AUTOMATICOUTPUT_ENABLE;
    if (HAL_TIMEx_ConfigBreakDeadTime(&htim1, &sBreakDeadTimeConfig) != HAL_OK)
        Error_Handler();

    HAL_TIM_MspPostInit(&htim1);
}

static void MX_GPIO_Init(void)
{
    GPIO_InitTypeDef GPIO_InitStruct = {0};

    __HAL_RCC_GPIOF_CLK_ENABLE();
    __HAL_RCC_GPIOA_CLK_ENABLE();
    __HAL_RCC_GPIOB_CLK_ENABLE();

    /* PA4 = status LED (unused for now) */
    HAL_GPIO_WritePin(GPIOA, GPIO_PIN_4 | GPIO_PIN_9, GPIO_PIN_RESET);
    HAL_GPIO_WritePin(GPIOB, GPIO_PIN_13 | GPIO_PIN_14, GPIO_PIN_RESET);

    GPIO_InitStruct.Pin   = GPIO_PIN_4 | GPIO_PIN_9;
    GPIO_InitStruct.Mode  = GPIO_MODE_OUTPUT_PP;
    GPIO_InitStruct.Pull  = GPIO_NOPULL;
    GPIO_InitStruct.Speed = GPIO_SPEED_FREQ_LOW;
    HAL_GPIO_Init(GPIOA, &GPIO_InitStruct);

    GPIO_InitStruct.Pin   = GPIO_PIN_13 | GPIO_PIN_14;
    GPIO_InitStruct.Mode  = GPIO_MODE_OUTPUT_PP;
    GPIO_InitStruct.Pull  = GPIO_NOPULL;
    GPIO_InitStruct.Speed = GPIO_SPEED_FREQ_LOW;
    HAL_GPIO_Init(GPIOB, &GPIO_InitStruct);
}

void Error_Handler(void)
{
    /* USER CODE BEGIN Error_Handler_Debug */
    __disable_irq();
    while (1) {}
    /* USER CODE END Error_Handler_Debug */
}

#ifdef USE_FULL_ASSERT
void assert_failed(uint8_t *file, uint32_t line)
{
}
#endif

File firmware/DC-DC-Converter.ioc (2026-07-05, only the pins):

Mcu.UserName=STM32G431C8Tx
PA11.Signal=USB_DM
PA12.Signal=USB_DP
PA4.Signal=GPIO_Output
PA8.Signal=S_TIM1_CH1
PA9.Signal=GPIO_Output
PB13.Signal=TIM1_CH1N
PB14.Signal=GPIO_Output
PB15.Signal=ADC2_IN15
PF0-OSC_IN.Signal=ADC1_IN10

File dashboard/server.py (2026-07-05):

import asyncio
import serial
import websockets
import json

PORT = "COM6"
BAUDRATE = 115200

def parse_line(line):
    """Parse 'VIN:12000 VOUT:5000 TARGET:6000 DUTY:165'"""
    data = {}
    try:
        parts = line.strip().split()
        for part in parts:
            if ":" in part:
                key, val = part.split(":", 1)
                data[key] = int(val)
    except:
        pass
    return data

async def handler(websocket):
    print(f"[WS] Client connecté : {websocket.remote_address}")
    try:
        ser = serial.Serial(PORT, BAUDRATE, timeout=0.1)
        print(f"[SERIAL] Port {PORT} ouvert")
    except Exception as e:
        print(f"[SERIAL] Erreur ouverture {PORT} : {e}")
        await websocket.send(json.dumps({"error": f"Impossible d'ouvrir {PORT}"}))
        return

    async def read_serial():
        loop = asyncio.get_event_loop()
        while True:
            try:
                line = await loop.run_in_executor(None, ser.readline)
                line = line.decode("utf-8", errors="ignore").strip()
                if line:
                    data = parse_line(line)
                    if data:
                        await websocket.send(json.dumps(data))
            except Exception as e:
                print(f"[SERIAL] Erreur lecture : {e}")
                break

    async def read_ws():
        async for message in websocket:
            try:
                print(f"[WS] Reçu : {message}")
                ser.write((message + "\r\n").encode("utf-8"))
            except Exception as e:
                print(f"[SERIAL] Erreur écriture : {e}")
                break

    try:
        await asyncio.gather(read_serial(), read_ws())
    finally:
        ser.close()
        print(f"[SERIAL] Port {PORT} fermé")

async def main():
    print("=" * 40)
    print("  STM32 Dashboard Backend")
    print(f"  Port série : {PORT}")
    print(f"  WebSocket  : ws://localhost:8765")
    print("=" * 40)
    async with websockets.serve(handler, "localhost", 8765):
        await asyncio.Future()

if __name__ == "__main__":
    asyncio.run(main())

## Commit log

2026-07-07 Add schematic PDF
2026-07-07 Modification of the Schematic PDF
